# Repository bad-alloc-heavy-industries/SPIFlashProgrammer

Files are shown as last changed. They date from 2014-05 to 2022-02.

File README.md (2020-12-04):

# SPI Flash Programmer

After a complete rewrite and re-hash of the original ideal having had it proove itself, a PCB and tightly integrated yet simple to use firmware is the name of the game.

SPIFlashProgrammer is a small but capable board housing a Texas Instruments Tiva-C series ARM microprocessor, two Flash devices for use in a production environment to allow one board to program up to two different target devices on a production line, and USB for power and connecting to a host machine.

When connected to a host, the USB connectivity and `flashprog` utility come together to form a sleak programming experience, allowing the tool to be used in a "set and forget" manner for test and debug of bitstreams and firmware.

## Flash chip support

The firmware targets 25 series memory devices such as the M25P16, W25Q80BV, and AT25SF641.

## Build and installation

Building requires a small number of prerequsites and dependencies:

* [Meson](https://meson.build)
* [Ninja](https://ninja-build.org)
* A modern arm-none-eabi GCC such as the [GNU ARM Embedded Toolchain](https://developer.arm.com/tools-and-software/open-source-software/developer-tools/gnu-toolchain/gnu-rm)
	or any distro or custom build GCC capable of targeting ARMv7 via C++17

To build the firmware and host software, run

```Bash
meson build --cross-file=cross-files/arm-none-eabi.meson
ninja -C build
```

You may then use the results in-place, or install the host software with `ninja -C build install`.

Programming the firmware onto a newly minted board can be achived via any JTAG adapter that can talk TI ICDI.
We use the awesome [Black Magic Probe](https://github.com/blacksphere/blackmagic) with the toolchain GDB.

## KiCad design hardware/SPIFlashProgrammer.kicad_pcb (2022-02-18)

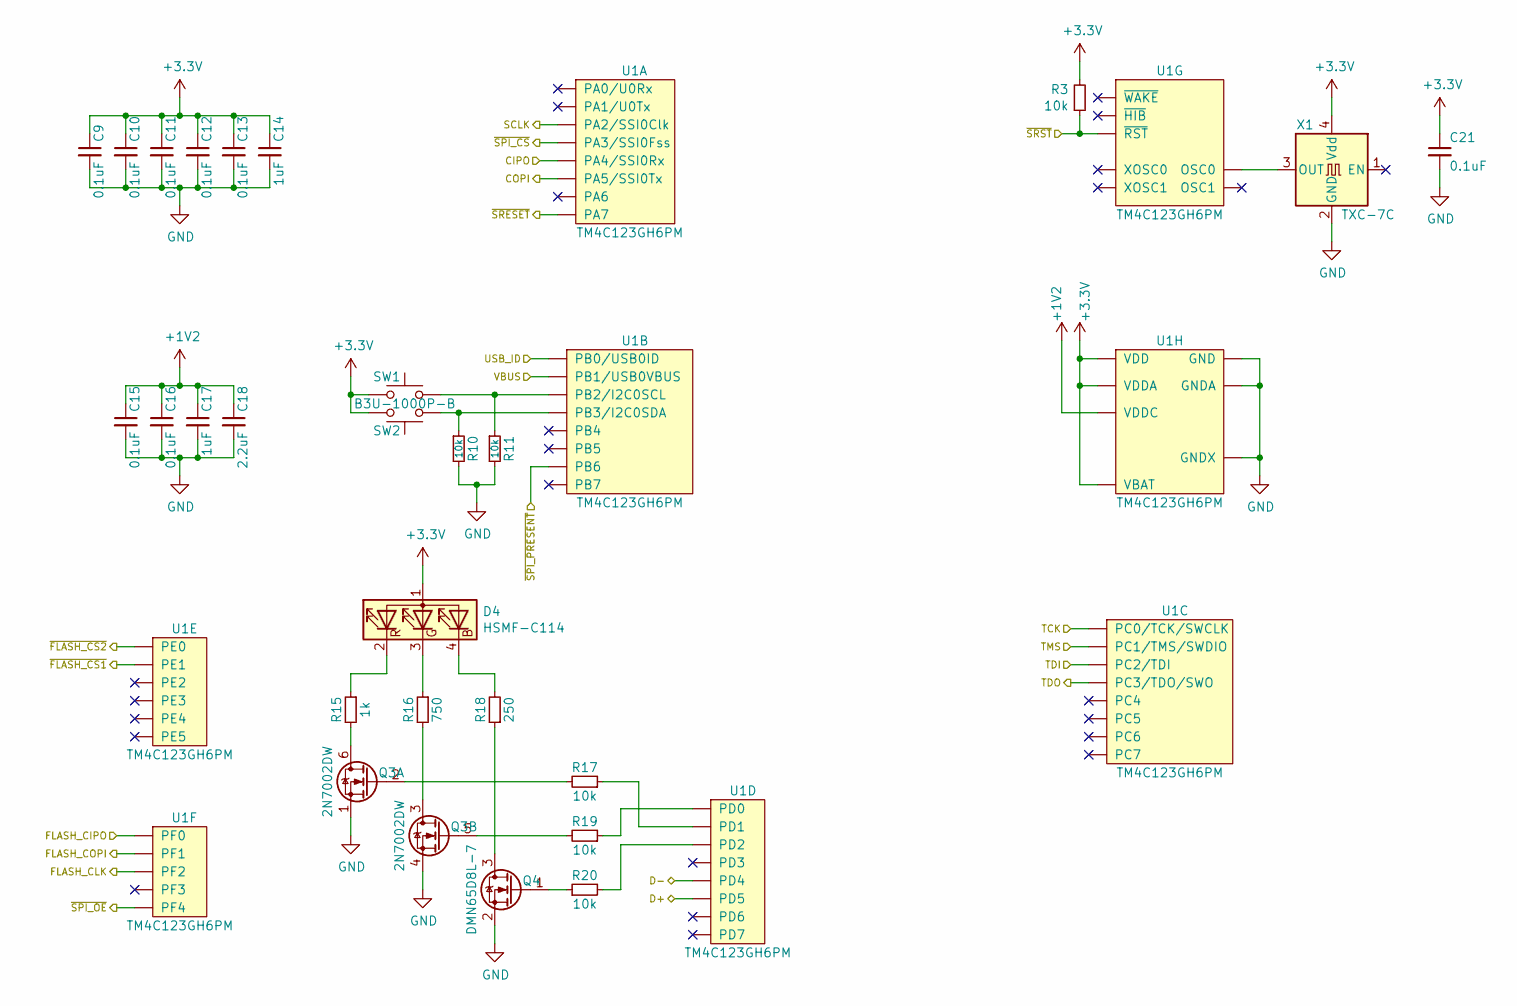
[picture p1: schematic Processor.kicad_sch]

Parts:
C9, C10, C11, C12, C13, C15, C16, C21: 0.1uF; C0603; MPN MC0603B104J250CT
C14, C17: 1uF; C0603; MPN MC0603B105K160CT
C18: 2.2uF; C0603; MPN C1608X5R1C225K080AB
D4: HSMF-C114; LED0606; MPN HSMF-C114
Q3: 2N7002DW; SOT-363_SC-70-6; MPN 2N7002DW
Q4: DMN65D8L-7; SOT-23; MPN DMN65D8L-7
R3, R10, R11, R17, R19, R20: 10k; R0603; MPN MC0063W0603110K
R15: 1k; R0603; MPN MC0063W0603110K
R16: 750; R0603; MPN MC0063W0603110K
R18: 250; R0603; MPN MC0063W0603110K
SW1, SW2: B3U-1000P-B; MPN B3U-1000P-B
U1: TM4C123GH6PM; QFP-64_10.2x10.2_Pitch0.5mm; MPN TM4C123GH6PM
X1: TXC-7C; SMD3225; MPN MCSJK-3N-25.00-3.3-50-B

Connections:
+1V2: C15.1, C16.1, C17.1, C18.1, U1.25 (VDDC), U1.56 (VDDC)
+3V3: C9.1, C10.1, C11.1, C12.1, C13.1, C14.1, C21.1, D4.1 (A), R3.2, SW1.1, SW2.1, U1.2 (VDDA), U1.11 (VDD), U1.26 (VDD), U1.37 (VBAT), U1.42 (VDD), U1.54 (VDD), X1.4 (Vdd); also elsewhere on the board
/Connectors/CIPO: U1.21 (PA4/SSI0Rx); also elsewhere on the board
/Connectors/COPI: U1.22 (PA5/SSI0Tx); also elsewhere on the board
/Connectors/D+: U1.44 (PD5); also elsewhere on the board
/Connectors/D-: U1.43 (PD4); also elsewhere on the board
/Connectors/SCLK: U1.19 (PA2/SSI0Clk); also elsewhere on the board
/Connectors/TCK: U1.52 (PC0/TCK/SWCLK); also elsewhere on the board
/Connectors/TDI: U1.50 (PC2/TDI); also elsewhere on the board
/Connectors/TDO: U1.49 (PC3/TDO/SWO); also elsewhere on the board
/Connectors/TMS: U1.51 (PC1/TMS/SWDIO); also elsewhere on the board
/Connectors/USB_ID: U1.45 (PB0/USB0ID); also elsewhere on the board
/Connectors/VBUS: U1.46 (PB1/USB0VBUS); also elsewhere on the board
/Connectors/~SPI_CS: U1.20 (PA3/SSI0Fss); also elsewhere on the board
/Connectors/~SPI_OE: U1.5 (PF4); also elsewhere on the board
/Connectors/~SPI_PRESENT: U1.1 (PB6); also elsewhere on the board
/Connectors/~SRESET: U1.24 (PA7); also elsewhere on the board
/Connectors/~SRST: R3.1, U1.38 (~RST); also elsewhere on the board
/Onboard Flash/CIPO: U1.28 (PF0); also elsewhere on the board
/Onboard Flash/COPI: U1.29 (PF1); also elsewhere on the board
/Onboard Flash/SCK: U1.30 (PF2); also elsewhere on the board
/Onboard Flash/~CS1: U1.8 (PE1); also elsewhere on the board
/Onboard Flash/~CS2: U1.9 (PE0); also elsewhere on the board
GND: C9.2, C10.2, C11.2, C12.2, C13.2, C14.2, C15.2, C16.2, C17.2, C18.2, C21.2, Q3.1 (S), Q3.4 (S), Q4.2 (S), R10.2, R11.2, U1.3 (GNDA), U1.12 (GND), U1.27 (GND), U1.35 (GNDX), U1.39 (GND), U1.55 (GND), X1.2 (GND); also elsewhere on the board
unnamed: D4.2 (RK), R15.1
unnamed: D4.3 (GK), R16.1
unnamed: D4.4 (BK), R18.2
unnamed: Q3.2 (G), R17.2
unnamed: Q3.3 (D), R16.2
unnamed: Q3.5 (G), R19.2
unnamed: Q3.6 (D), R15.2
unnamed: Q4.1 (G), R20.1
unnamed: Q4.3 (D), R18.1
unnamed: R10.1, SW2.2, U1.48 (PB3/I2C0SDA)
unnamed: R11.1, SW1.2, U1.47 (PB2/I2C0SCL)
unnamed: R17.1, U1.62 (PD1)
unnamed: R19.1, U1.61 (PD0)
unnamed: R20.2, U1.63 (PD2)
unnamed: U1.40 (OSC0), X1.3 (OUT)

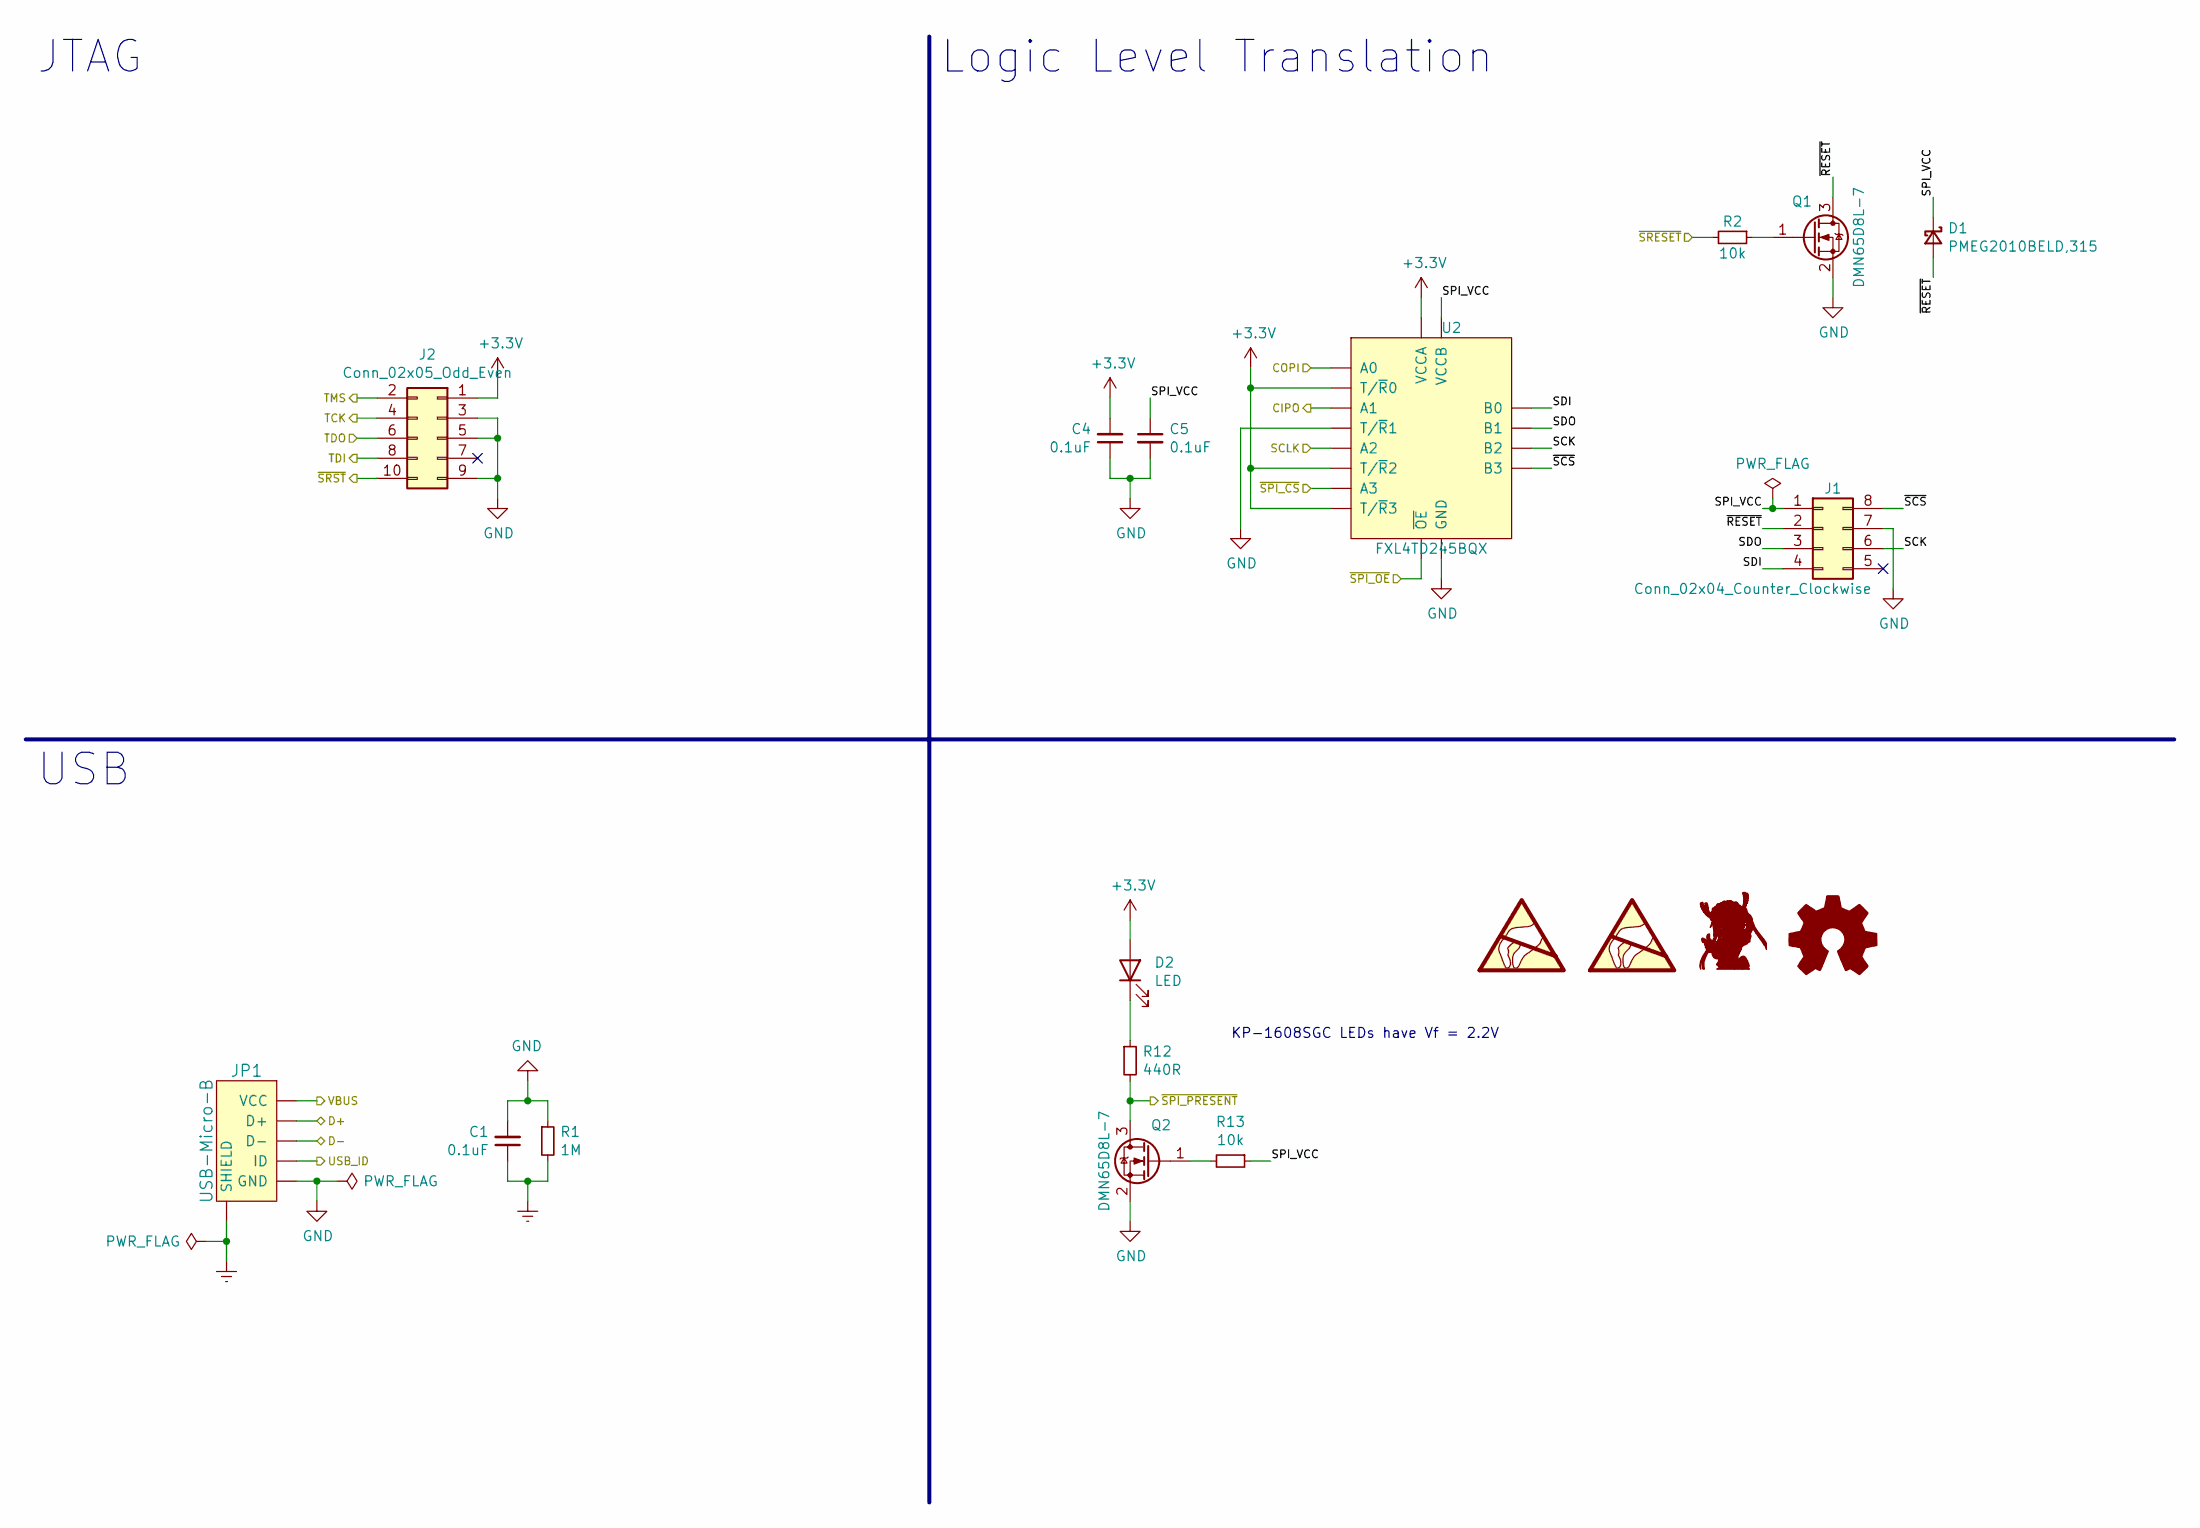
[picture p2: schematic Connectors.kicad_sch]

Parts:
C1, C4, C5: 0.1uF; C0603; MPN MC0603B104J250CT
D1: PMEG2010BELD,315; SOD882D_DFN1006D-2; MPN PMEG2010BELD,315
D2: LED; LED0603; MPN KP-1608SGC
DRG1: トール; トール-8.6x9.9
J1: Conn_02x04_Counter_Clockwise; 75867-132LF; MPN 75867-132LF
J2: Conn_02x05_Odd_Even; PinSocket_2x05_P1.27mm_Vertical_SMD; MPN 20021321-00010C4LF
JP1: USB-Micro-B; MICRO-USB-B-(IN_PCB); MPN 10103593-0001LF
LOGO1: Logo_Open_Hardware_Small; OSHW-Symbol_6.7x6mm_SilkScreen
Q1, Q2: DMN65D8L-7; SOT-23; MPN DMN65D8L-7
R1: 1M; R0603; MPN MCWR06X1004FTL
R2, R13: 10k; R0603; MPN MC0063W0603110K
R12: 440R; R0603; MPN MCWR06X4700FTL
SYM1: SYM_ESD_Small; WEEE-Logo_4.2x6mm_SilkScreen
SYM2: SYM_ESD_Small; ESD-Logo_6.6x6mm_SilkScreen
U2: FXL4TD245BQX; DQFN16_1EP_2.5x3.5mm_P0.5mm; MPN FXL4TD245BQX

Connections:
+3V3: C4.2, D2.2 (A), J2.1, U2.1 (VCCA), U2.2 (T/~R0), U2.7 (T/~R3), U2.10 (T/~R2); also elsewhere on the board
/Connectors/CIPO: U2.4 (A1); also elsewhere on the board
/Connectors/COPI: U2.3 (A0); also elsewhere on the board
/Connectors/D+: JP1.D+; also elsewhere on the board
/Connectors/D-: JP1.D-; also elsewhere on the board
/Connectors/SCK: J1.6, U2.12 (B2)
/Connectors/SCLK: U2.5 (A2); also elsewhere on the board
/Connectors/SDI: J1.4, U2.14 (B0)
/Connectors/SDO: J1.3, U2.13 (B1)
/Connectors/SPI_VCC: C5.1, D1.1 (K), J1.1, R13.1, U2.16 (VCCB)
/Connectors/TCK: J2.4; also elsewhere on the board
/Connectors/TDI: J2.8; also elsewhere on the board
/Connectors/TDO: J2.6; also elsewhere on the board
/Connectors/TMS: J2.2; also elsewhere on the board
/Connectors/USB_ID: JP1.ID; also elsewhere on the board
/Connectors/VBUS: JP1.VCC; also elsewhere on the board
/Connectors/~RESET: D1.2 (A), J1.2, Q1.3 (D)
/Connectors/~SCS: J1.8, U2.11 (B3)
/Connectors/~SPI_CS: U2.6 (A3); also elsewhere on the board
/Connectors/~SPI_OE: U2.9 (~OE); also elsewhere on the board
/Connectors/~SPI_PRESENT: Q2.3 (D), R12.2; also elsewhere on the board
/Connectors/~SRESET: R2.2; also elsewhere on the board
/Connectors/~SRST: J2.10; also elsewhere on the board
Earth: C1.1, JP1.SHIELD, R1.2
GND: C1.2, C4.1, C5.2, J1.7, J2.3, J2.5, J2.9, JP1.GND1 (GND), Q1.2 (S), Q2.2 (S), R1.1, U2.8 (GND), U2.15 (T/~R1), U2.EP (GND); also elsewhere on the board
unnamed: D2.1 (K), R12.1
unnamed: Q1.1 (G), R2.1
unnamed: Q2.1 (G), R13.2

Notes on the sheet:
JTAG
USB
KP-1608SGC LEDs have Vf = 2.2V
Logic Level Translation

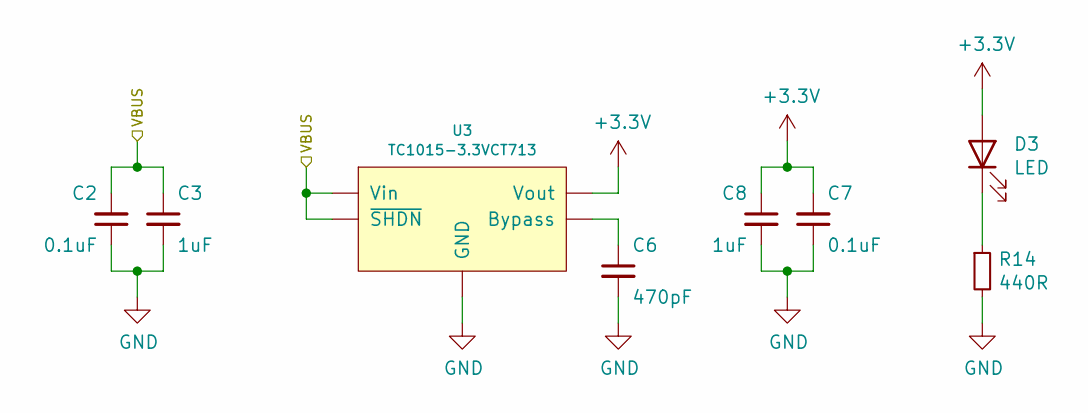
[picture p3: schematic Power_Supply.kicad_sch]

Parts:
C2, C7: 0.1uF; C0603; MPN MC0603B104J250CT
C3, C8: 1uF; C0603; MPN MC0603B105K160CT
C6: 470pF; C0603; MPN MC0603B471J500CT
D3: LED; LED0603; MPN KP-1608SGC
R14: 440R; R0603; MPN MCWR06X4700FTL
U3: TC1015-3.3VCT713; SOT-23-5; MPN TC1015-3.3VCT713

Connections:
+3V3: C7.2, C8.1, D3.2 (A), U3.5 (Vout); also elsewhere on the board
/Connectors/VBUS: C2.2, C3.1, U3.1 (Vin), U3.3 (~SHDN); also elsewhere on the board
GND: C2.1, C3.2, C6.2, C7.1, C8.2, R14.2, U3.2 (GND); also elsewhere on the board
unnamed: C6.1, U3.4 (Bypass)
unnamed: D3.1 (K), R14.1

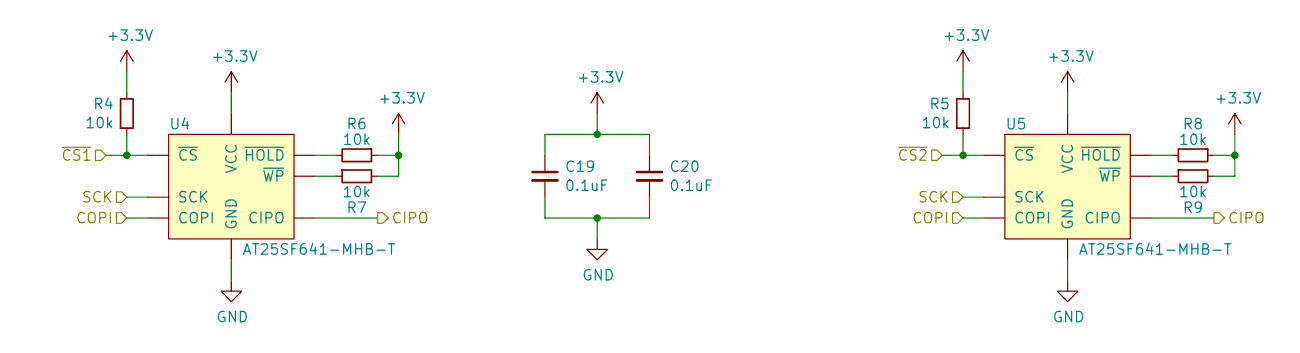
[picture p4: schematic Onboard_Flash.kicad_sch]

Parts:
C19, C20: 0.1uF; C0603; MPN MC0603B104J250CT
R4, R5, R6, R7, R8, R9: 10k; R0603; MPN MC0063W0603110K
U4, U5: AT25SF641-MHB-T; UDFN-8-1EP_6x5mm_P1.27mm_EP3.4x4mm; MPN AT25SF641-MHB-T

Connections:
+3V3: C19.1, C20.1, R4.2, R5.2, R6.1, R7.2, R8.1, R9.2, U4.8 (VCC), U5.8 (VCC); also elsewhere on the board
/Onboard Flash/CIPO: U4.2 (CIPO), U5.2 (CIPO); also elsewhere on the board
/Onboard Flash/COPI: U4.5 (COPI), U5.5 (COPI); also elsewhere on the board
/Onboard Flash/SCK: U4.6 (SCK), U5.6 (SCK); also elsewhere on the board
/Onboard Flash/~CS1: R4.1, U4.1 (~CS); also elsewhere on the board
/Onboard Flash/~CS2: R5.1, U5.1 (~CS); also elsewhere on the board
GND: C19.2, C20.2, U4.4 (GND), U4.9 (GND), U5.4 (GND), U5.9 (GND); also elsewhere on the board
unnamed: R6.2, U4.7 (~HOLD)
unnamed: R7.1, U4.3 (~WP)
unnamed: R8.2, U5.7 (~HOLD)
unnamed: R9.1, U5.3 (~WP)

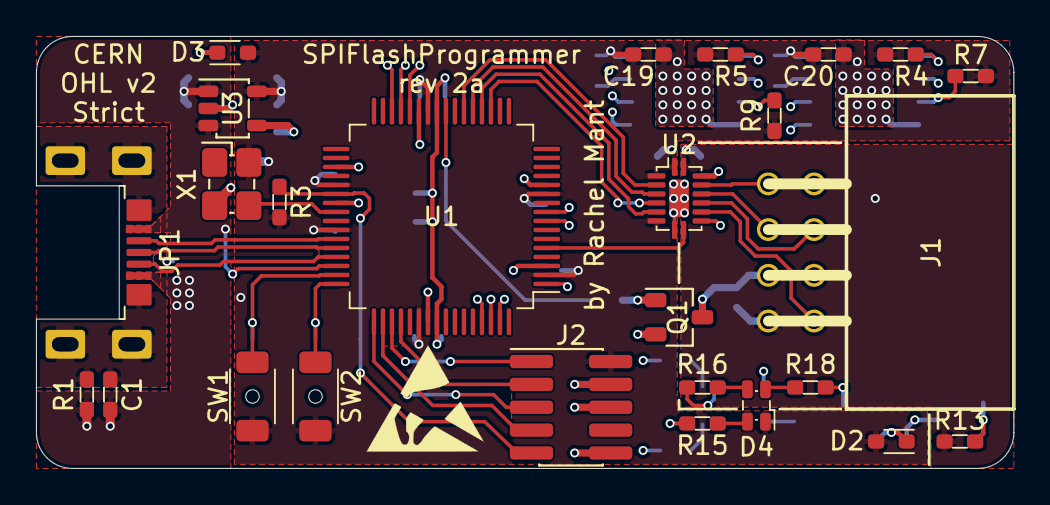
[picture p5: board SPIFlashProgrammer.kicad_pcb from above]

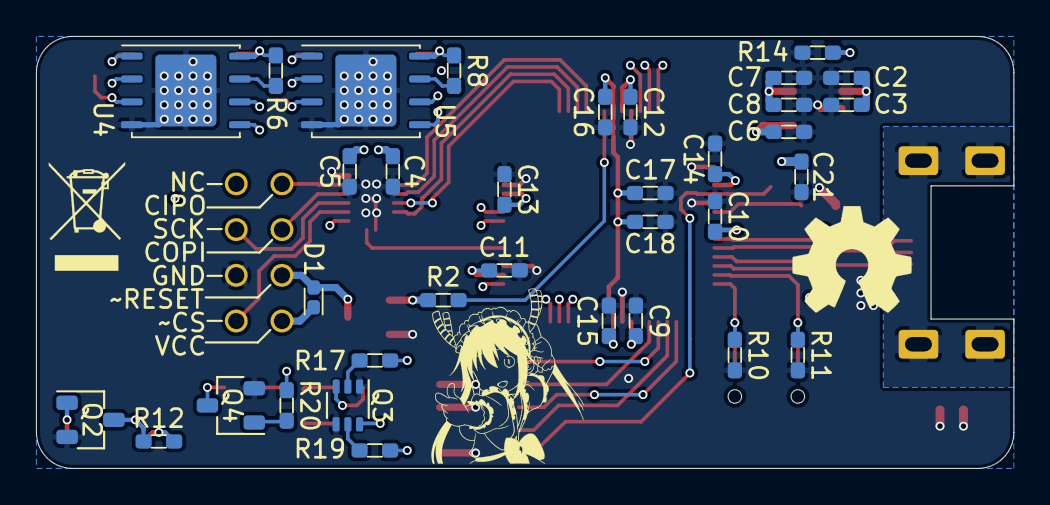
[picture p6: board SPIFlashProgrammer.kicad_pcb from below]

Board: 4 copper layers, 54.3 x 24.0 mm, 64 parts (37 on the bottom side), 55 nets.

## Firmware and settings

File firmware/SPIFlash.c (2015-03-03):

/*
 * This file is part of SPI Flash Programmer (SPIFP)
 * Copyright © 2014 Rachel Mant (dx-mon@users.sourceforge.net)
 *
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
 * You should have received a copy of the GNU General Public License
 * along with this program.  If not, see <http://www.gnu.org/licenses/>.
 */

#include <stdint.h>
#include <stddef.h>
#include <stdbool.h>
#ifndef NOCONFIG
#include "config.h"
#endif
#ifndef NOUSB
#include "USBInterface.h"
#include "UART.h"
#endif
#include "SPI.h"
#include "GPIO.h"

typedef enum
{
	DEV_INVALID,
	DEV_M25P80,
	DEV_M25P16,
	DEV_W25Q80BV,
} FlashDevice_t;

#define WREN	0x06
#define WRDI	0x04
/* 0x9F is the JEDEC guaranteed instruction for reading device ID info. */
#define RDID	0x9F
#define RDSR	0x05
#define WRSR	0x01
#define READ	0x03
#define PP		0x02
#define SSE		0x20
#define SE		0xD8
#define BE		0xC7

FlashDevice_t device;
#ifndef NOUSB
uint8_t usbData[256];
uint32_t usbDataTotal;
uint32_t usbDataReceived;
#endif

/*
 * 0x20 => Manufacturer ID (Numonyx)
 * 0x20 => Memory Type (SPI Flash)
 * 0x14 => Memory Capacity - 8Mbit
 */
static const uint8_t M25P80_DID[3] = { 0x20, 0x71, 0x14 };
/*
 * 0x20 => Manufacturer ID (Numonyx)
 * 0x20 => Memory Type (SPI Flash)
 * 0x15 => Memory Capacity - 16Mbit
 */
static const uint8_t M25P16_DID[3] = { 0x20, 0x20, 0x15 };
/*
 * 0xEF => Winbond
 * 0x40 => SPIFlash
 * 0x14 => 8Mbit
 */
static const uint8_t W25Q80BV_DID[3] = { 0xEF, 0x40, 0x14 };

int datacmp(const uint8_t *a, const uint8_t *b, const size_t n)
{
	size_t i;
	for (i = 0; i < n; i++)
	{
		if (*a != *b)
			return *a - *b;
		a++;
		b++;
	}
	return 0;
}

#ifndef NOUSB
uint16_t readData()
{
	uint8_t pageLen, i;
	if (uartRead() != CMD_PAGE)
		return 0;
	pageLen = uartRead();
	i = 0;
	do
	{
		usbData[i] = uartRead();
		i++;
	}
	while (i != pageLen);

	if (pageLen == 0)
		return 0x100;
	else
		return pageLen;
}
#endif

bool verifyDID()
{
	uint8_t data[3], i;
	/* Select the device */
	spiChipSelect(true);
	/* Send a JEDEC DID read request */
	spiWrite(RDID);
	/* For each of the three bytes returned */
	for (i = 0; i < 3; i++)
		/* And having recieved the answer, buffer it */
		data[i] = spiRead();
	/* Deselect the device */
	spiChipSelect(false);
	/* Compare the recieved data to the expected data */
	/* I wanted to use memcmp here, but could not make use of the newlib implemenation */
	if (datacmp(data, M25P80_DID, 3) == 0)
		device = DEV_M25P80;
	else if (datacmp(data, M25P16_DID, 3) == 0)
		device = DEV_M25P16;
	else if (datacmp(data, W25Q80BV_DID, 3) == 0)
		device = DEV_W25Q80BV;
	else
		device = DEV_INVALID;
	return device != DEV_INVALID;
}

void writeEnable()
{
	/* Select the device */
	spiChipSelect(true);
	/* Write enable the device */
	spiWrite(WREN);
	/* Deselect the device - executes write-enable instruction */
	spiChipSelect(false);
	asm("nop");
	/* Select the device again */
	spiChipSelect(true);
	/* Issue Read Status Register instruction */
	spiWrite(RDSR);
	/* And use it's continuous read mode till the write enable completes (bit 1 => 1) */
	while ((spiRead() & 0x02) == 0);
	/* Deselect the device */
	spiChipSelect(false);
}

void unlockDevice()
{
	writeEnable();
	/* Select the device */
	spiChipSelect(true);
	/* Write the Status Register */
	spiWrite(WRSR);
	/* All zeros disables all enabled protections */
	spiWrite(0x00);
	/* Deselect the device */
	spiChipSelect(false);
}

void lockDevice()
{
	writeEnable();
	/* Select the device */
	spiChipSelect(true);
	/* Write the Status Register */
	spiWrite(WRSR);
	/* The three Block Protect bits are bits [4:2] */
	spiWrite(0x1C);
	/* Deselect the device */
	spiChipSelect(false);
}

void eraseDevice(const uint8_t *data)
{
	uint8_t i;
	/* Ensure the device is write enabled */
	writeEnable();
	/* Select the device */
	spiChipSelect(true);
	/* Issue erase instruction */
	spiWrite(BE);
	/* Deselect the device - executes erase */
	spiChipSelect(false);
	for (i = 0; i < 10; i++);
	/* Select the device */
	spiChipSelect(true);
	/* Write the Read Status Register instruction */
	spiWrite(RDSR);
	/* While write is not complete (bit 0 => 1) */
	while ((spiRead() & 0x01) != 0)
	{
#ifndef NOUSB
		if (data == usbData && uartHaveData())
		{
			/* It doesn't matter what the request was.. */
			uartRead();
			/* Inform the connected PC */
			uartWrite(CMD_ERASE);
			uartWrite(RPL_BUSY);
		}
#endif
	}
	/* Deselect the device */
	spiChipSelect(false);
#ifndef NOUSB
	if (data == usbData)
	{
		/* It doesn't matter what the request was.. */
		uartRead();
		/* Write complete, so say erase completed! */
		uartWrite(CMD_ERASE);
		uartWrite(RPL_OK);
	}
#endif
}

void writeData(const uint8_t sector, const uint8_t page, const uint8_t *data, const uint16_t dataLen)
{
	uint16_t i;
	writeEnable();
	/* Select the device */
	spiChipSelect(true);
	/* And issue the Page Program instruction */
	spiWrite(PP);
	/* Sector is (sector >> 4), and sub-sector is (sector & 0x0F) */
	spiWrite(sector);
	/* The page of the sector */
	spiWrite(page);
	/* Must be 0 to select the first byte of the page */
	spiWrite(0);
	/* Send the data */
	for (i = 0; i < dataLen; i++)
		spiWrite(data[i]);
	/* Deselect the device - executes write instruction */
	spiChipSelect(false);
}

bool verifyData(const uint16_t startPage, const uint8_t *data, const size_t dataLen)
{
	uint16_t i;
	bool ok = true;
	/* Select the device */
	spiChipSelect(true);
	spiWrite(READ);
	spiWrite(startPage >> 8);
	spiWrite(startPage & 0xFF);
	spiWrite(0);
	for (i = 0; i < dataLen; i++)
	{
		if (spiRead() != data[i])
		{
			ok = false;
			break;
		}
	}
	/* Deselect the device */
	spiChipSelect(false);
	return ok;
}

void waitWriteComplete()
{
	/* Select the device */
	spiChipSelect(true);
	/* Write the Read Status Register instruction */
	spiWrite(RDSR);
	/* And use it's continuous read mode till the write is complete (bit 0 => 0) */
	while ((spiRead() & 0x01) != 0);
	/* Deselect the device */
	spiChipSelect(false);
}

void transferBitfile(const void *data, const size_t dataLen)
{
	uint16_t addr, pages;
#ifndef NOCONFIG
	const uint8_t *dataPtr = data;
#endif
#ifndef NOUSB
	bool programmed = true;
#endif

	if (!verifyDID())
	{
#ifndef NOUSB
		if (data == usbData)
		{
			uartWrite(CMD_ABORT);
			uartWrite(RPL_FAIL);
		}
#endif
		return;
	}
#ifndef NOUSB
	else if (data == usbData)
	{
		uartWrite(CMD_START);
		uartWrite(RPL_OK);
	}
#endif

	pages = (dataLen >> 8) + ((dataLen & 0xFF) != 0 ? 1 : 0);
	if (device == DEV_M25P80)
	{
		unlockDevice();
		waitWriteComplete();
	}
	eraseDevice(data);
	for (addr = 0; addr < pages; addr++)
	{
#ifndef NOUSB
		size_t pageLen;
		if (data == usbData)
		{
			pageLen = readData();
			/* If we failed to receive the page, immediately indicate failure */
			if (pageLen == 0)
			{
				uartWrite(CMD_PAGE);
				uartWrite(RPL_FAIL);
				programmed = false;
				break;
			}
			writeData(addr >> 8, addr & 0xFF, data, pageLen);
		}
#endif
#ifndef NOCONFIG
		if (data == config)
		{
			if ((addr + 1) < (dataLen >> 8))
				writeData(addr >> 8, addr & 0xFF, dataPtr, 256);
			else
				writeData(addr >> 8, addr & 0xFF, dataPtr, dataLen & 0xFF);
			dataPtr += 256;
		}
#endif
		waitWriteComplete();
#ifndef NOUSB
		if (data == usbData)
		{
			if (!verifyData(addr, data, pageLen))
			{
				uartWrite(CMD_ABORT);
				uartWrite(RPL_FAIL);
				programmed = false;
				break;
			}
			else
			{
				uartWrite(CMD_PAGE);
				uartWrite(RPL_OK);
				usbDataReceived += pageLen;
			}
		}
#endif
	}
	if (device == DEV_M25P80)
	{
		lockDevice();
		waitWriteComplete();
	}
#ifndef NOCONFIG
	if (data == config)
	{
		if (verifyData(0, data, dataLen))
			gpioShowOK();
	}
#endif
#ifndef NOUSB
	if (data == usbData)
	{
		uint8_t cmd = uartRead();
		if (cmd == CMD_STOP)
		{
			uint8_t i;
			uint32_t diff = usbDataTotal - usbDataReceived;
			for (i = 0; i < 4; i++)
			{
				uartWrite((diff >> 24) & 0xFF);
				diff <<= 8;
			}
			uartWrite(CMD_STOP);
			if (programmed)
			{
				uartWrite(RPL_OK);
				gpioShowOK();
			}
			else
				uartWrite(RPL_FAIL);
		}
		else
		{
			uartWrite(CMD_INVALID);
			uartWrite(RPL_FAIL);
		}
	}
#endif
}

int main()
{
	gpioInit();
	spiInit();
#ifndef NOUSB
	uartInit();
#endif

	while (1)
	{
#ifndef NOCONFIG
		/* If either button has been pressed.. */
		if (gpioCanTransfer())
		{
			gpioStopTimer();
			gpioBeginTransfer();
			gpioSignalTransfer();
			/* Attempt the transfer */
			transferBitfile(config, configLen);
			gpioEndTransfer();
			gpioStartTimer();
		}
#endif
#ifndef NOUSB
		/* If the UART has recieved a byte.. */
		if (uartHaveData())
		{
			if (uartPeak() == CMD_START)
			{
				uint8_t i;
				gpioStopTimer();
				gpioBeginTransfer();
				usbDataTotal = 0;
				usbDataReceived = 0;
				for (i = 0; i < 4; i++)
				{
					usbDataTotal <<= 8;
					usbDataTotal |= uartRead();
				}
				gpioSignalTransfer();
				transferBitfile(usbData, usbDataTotal);
				gpioEndTransfer();
				gpioStartTimer();
			}
			else
			{
				uartWrite(CMD_INVALID);
				uartWrite(RPL_FAIL);
			}
		}
#endif
		gpioCheckIdle();
	}

	return 0;
}

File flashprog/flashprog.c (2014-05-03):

/*
 * This file is part of SPI Flash Programmer (SPIFP)
 * Copyright © 2014 Rachel Mant (dx-mon@users.sourceforge.net)
 *
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
 * You should have received a copy of the GNU General Public License
 * along with this program.  If not, see <http://www.gnu.org/licenses/>.
 */

#include <stdio.h>
#include <fcntl.h>
#include <unistd.h>
#include <sys/types.h>
#include <sys/stat.h>

#include "strUtils.h"
#include "USB.h"
#include "USBInterface.h"

#ifdef _MSC_VER
#define _usleep _sleep
#else
#define MSECS_IN_SEC 1000
#define NSECS_IN_MSEC 1000000
#define _usleep(milisec) \
	{\
		struct timespec req = {milisec / MSECS_IN_SEC, (milisec % MSECS_IN_SEC) * NSECS_IN_MSEC}; \
		nanosleep(&req, NULL); \
	}
#endif

/*
 * USB transfer protocol:
 *
 * CMD_START + 4 bytes => uint32_t length of data total
 * CMD_PAGE + 1 bytes + up to 256 bytes => uint8_t page length (0 == 256), page data
 * CMD_ABORT => Sent to indicate user requested to abort
 * CMD_STOP => Sent at the end of transfering all the data to indicate we think we've finished.
 *   Device replies with some data indicating the status of the flash device and if there are any remaining expected bytes.
 *
 * After sending each command, including CMD_STOP, the device must respond with the command code and a byte indicating whether
 * it could execute it correctly - 1 for OK, 0 for error.
 */
int dataFD;
size_t dataLen;

/* Reserve enough space for a page of data */
unsigned char data[256];

static const uint8_t numProgChars = 4;
static const char *progressChars = "|/-\\";
uint8_t progChar;

int usage(char *prog)
{
	printf("Usage:\n"
		"\t%s binfile.bin\n", prog);
	return 1;
}

void tick()
{
	printf("%c\b", progressChars[progChar]);
	fflush(stdout);
	progChar = ++progChar % numProgChars;
}

void processFile()
{
	int32_t res, blockLen = -1;
	uint32_t pageNum = 0;
	progChar = 0;
	printf("Programming: ");
	while (blockLen != 0)
	{
		blockLen = read(dataFD, data, 256);
		if (blockLen == -1)
		{
			usbWriteByte(CMD_ABORT);
			die("\rError: read() returned an error.. cannot continue..\n");
		}
		else if (blockLen == 0)
			continue;
		usbWriteByte(CMD_PAGE);
		usbWriteByte(blockLen & 0xFF);
		usbWrite(data, blockLen);
		res = usbRead(data, 2);
		if (res != 2 || data[0] != CMD_PAGE || data[1] != RPL_OK)
		{
			printf("\rError: Programming a data page failed\n");
			break;
		}
		else
		{
			pageNum++;
			if ((pageNum % 4) == 0)
				tick();
		}
	}
}

void waitForErase()
{
	int32_t res;
	progChar = 0;
	printf("Erasing: ");
	fflush(stdout);
	do
	{
		usbWriteByte(CMD_ERASE);
		res = usbRead(data, 2);
		if (res != 2 || data[0] != CMD_ERASE)
			die("\rError: Erase cycle interrupted, cannot continue..\n");
		else if (data[1] == RPL_OK)
			break;
		tick();
		_usleep(100);
	}
	while (data[1] == RPL_BUSY);
	printf("Done!\n");
}

void writeLength()
{
	data[0] = (dataLen >> 24) & 0xFF;
	data[1] = (dataLen >> 16) & 0xFF;
	data[2] = (dataLen >> 8) & 0xFF;
	data[3] = dataLen & 0xFF;
	usbWrite(data, 4);
}

int main(int argc, char **argv)
{
	int32_t res;
	struct stat dataStat;

	if (argc != 2)
		return usage(argv[0]);
	usbInit();
	dataFD = open(argv[1], O_RDONLY | O_EXCL);
	if (dataFD == -1)
	{
		usbDeinit();
		die("Error: Could not open the file specified\n");
	}
	if (stat(argv[1], &dataStat) != 0)
	{
		close(dataFD);
		usbDeinit();
		die("Error: Could not determine the size of the file specified\n");
	}
	dataLen = dataStat.st_size;

	// Send the start command + 4 bytes indicating how long the data file is
	usbWriteByte(CMD_START);
	writeLength();
	// Now wait for the return code
	res = usbRead(data, 2);
	if (res != 2 || data[0] != CMD_START || data[1] != RPL_OK)
		printf("Tiva C Launchpad said it could not start a transfer\n");
	else
	{
		waitForErase();
		processFile();
		usbWriteByte(CMD_STOP);
		res = usbRead(data, 6);
		if (res != 6 || data[4] != CMD_STOP || data[5] != RPL_OK)
			printf("\rTiva C Launchpad encountered errors during programming, please try again\n");
		else if (*((uint32_t *)data) != 0)
			printf("\rTiva C Launchpad did not receieve whole file\n");
		else
			printf("Done!\n");
	}

	close(dataFD);
	usbDeinit();
	return 0;
}

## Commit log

2014-04-05 Initial commit of the SPI Flash programmer itself.
    Currently this just includes the code needed to intialise the Port A and F GPIO interfaces, and un-gate the SSI0 (SPI0) interface, configuring it as a Freescale SPI interface
2014-04-05 Enabled use of the two buttons on the dev board, and made it so that the LED can be switched to red or green on pressing the buttons (dependant on which is pressed)
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2014-04-06 Checked the datahseet for the SPI Flash device series, and altered the SPI configuration accordingly
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2014-04-06 Restructured the while loop code to activate on either button being pressed and going into the routine we'll use for transfering the bitfile
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2014-04-07 Configured Timer 0 A ready for use to control the timing of the LED reset
    [SPIFlash.c]
2014-04-07 Integrated the new timer configuration into the program to reset the LED back to blue regardless of success of failure after 500us from the completion of a cycle.
    [SPIFlash.c]
2014-04-07 Implemented my own varient of memcmp() named datacmp() and documented verifyDID(). Turns out I can't use my toolchain's libc in this configuration, or if I can I've not figured out how yet without cr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
    [SPIFlash.c]
2014-04-07 Corrected the Port A GPIO configuration to ensure that !CS is an output
    [SPIFlash.c]
2014-04-07 Refactored the SPI IO code into two functions that perform the nitty-gritty and a sequence of calls to those functions
2014-04-07 Added support for starting a write cycle to the SPI Flash device with Write Enable (WREN)
2014-04-07 Implemented a device erase function and support function to allow waiting on the operation to complete
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2014-04-07 Refactored the blob transfer code so it can take an arbitrary buffer rather than the fixed buffer system used before
    [SPIFlash.c]
2014-04-08 Reworked the buffer writer code so that support for the USB version of it is easy to add
    [SPIFlash.c]
2014-04-09 Implemented code for locating, opening and claiming (then cleaning up at the end) the Tiva C debug UART in flashprog
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2014-04-10 Removed the RS232 interface code as while a good idea, it turns out libusb has a better, more powerful transfer mechanism in libusb_bulk_transfer()
2014-04-10 Fixed the build system and removed code that causes the build to fail due to being incomplete
    [USB.c, flashprog.c]
2014-04-10 Added better error handling to the interface claim call in flashprog
    [USB.c]
2014-04-10 Corrected which interface and endpoints the USB IO interface uses
    [USB.c]
2014-04-10 Added configuration directives for enabling the UART on PA[0:1] to the firmware
2014-04-10 Corrected some documentation and wrapped the built-in configuration specific Port F code with #ifndef NOCONFIG
    [SPIFlash.c]
2014-04-10 Fixed an error in the checking logic for the CMD_STOP return value in flashprog
    [flashprog.c]
2014-04-10 Implemented functions to read and write the UART on the Tiva C
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2014-04-11 Implemented checking for programming start failure
    [SPIFlash.c]
2014-04-11 Fixed the insanity that was the preprocessor usage to implement the USB-buffer-specific sections of code in transferBitfile()
    [SPIFlash.c]
2014-04-11 Implemented stub support for handling programming failures during a USB-based programming run
    [SPIFlash.c]
2014-04-11 Corrected my code for handling the normal operation path after the call to verifyDID() on the Tiva C
    [SPIFlash.c]
2014-04-11 Fixed a bug in the UART IO code which was making my UART code think there was always a value waiting to be read in the buffer which results in crashing the processor
    [SPIFlash.c]
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2014-04-11 Added some rudimentary error reporting to the USB IO routines for flashprog
    [USB.c]
2014-04-12 Fixed the packing issue that comes about from different sized struct members causing gaps in the structure when padding is not switched off
    [USB.c]
2014-04-12 Added checks for the CDC structure and switched the interface associations structure to const
2014-04-12 Fixed the mess that was checking the extra_length member for both custom structures
    [USB.c]
2014-04-13 Created the initialisation control flow to set the USB-UART bridge baud rate, byte-width and other control components up in flashprog
2014-04-13 Fixed the reason why the USB IO code was not working - irritating little flaw in the firmware code that's burnt a weekend debugging it
    [SPIFlash.c]
2014-04-13 Added assurances that the correct configuration is entered into by the ICDI component of the interface
    [USB.c]
2014-04-15 Fixed the byte order of the bytes-remaining value sent back from the firmware
    [SPIFlash.c]
2014-04-15 Improved the error detection and reporting for flashprog
    [flashprog.c]
2014-04-15 Added all the code needed to support the transfer of the .bin file over the USB-UART link
2014-04-16 Fixed an error in the firmware which was making the firmware think that the first byte of the first page verified was wrong even when it wasn't
    [SPIFlash.c]
2014-04-16 Corrected how dataLen is transmitted from flashprog to the firmware
    [flashprog.c]
2014-04-16 Fixed the firmware as it was incorrectly issuing the Write Enable instruction - making it so that the instruction never executed
    [SPIFlash.c]
2014-04-19 Configured PA7 as a digital out to allow the Tiva C to reset the target
    [SPIFlash.c]
2014-04-19 Fixed all the SPI oopsies.. to work with the FPGA board, must be configured as Open Collector for data/chip select
    [SPIFlash.c]
2014-04-19 Fixed the SPI bus glitching on us
    [SPIFlash.c]
2014-04-19 Fixed the preprocessor logic surrounding PA7
    [SPIFlash.c]
2014-04-19 Final fixes for the SPI bus setup code to get the whole thing really stable
    [SPIFlash.c]
2014-05-03 Implemented a mechanism to allow for device erasure having not understood the timings for how long Bulk Erase (BE) takes. Datasheet for the Numonyx device this is tested against specifies 8-80s, or f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
    [SPIFlash.c, flashprog.c]
2014-05-03 Corrected the wait condition in waitWriteComplete() and added a call after lockDevice() so the instruction can be assured to have been executed
    [SPIFlash.c]
2014-05-03 Corrected the pin configuration for the SPI clock in the firmware
    [SPIFlash.c]
2014-05-03 Fixed the output of the programming function's error routines in flashprog so the newlines are in the right places
    [flashprog.c]
2014-05-03 Sped up the poll interval to 100ms from 1s in flashprog during device erase which is auto-initiated by the flashing firmware
2014-05-03 Fixed a couple of errors in the README file
2015-01-08 Fixed the precarious delay loop that is designed to wait for WREN completing by instead reading back the status register and waiting for the bit to become set there
    [SPIFlash.c]
2015-01-22 Restructured the build system for the firmware and moved the SPI routines into their own file to allow retargeting to other devices
2015-01-22 Moved the startup code for the Tiva C to it's new home and corrected the build system to match
    [Startup.c]
2015-01-22 Moved the Tiva C specific UART code into it's own file like the SPI code and compensated the build system and main firmware file to match
2015-01-22 Moved the UART initialistaion code for the Tiva C into uartInit() in it's implementation files
2015-01-22 Moved some more of the Tiva C specific UART code into the UART driver file specific to it
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2015-01-22 Added a missing initialisation statement to the UART code as I'd been too efficient at encoding the port direction gubbins
    [UART.c]
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2015-01-23 Added the header for the Tiva C used on the TI Tiva C Launchpad so builds can work out of the gate.
    PLEASE NOTE:
    The license in this file, due to it's origins in TI's TivaWareC pack, is currently likely incompatable with the broader license of this code so may need to be reworked in the future.
2015-02-06 Fixed an off-by-one in the vector handler table, added some missing irqEmptyDef entries and made the hard fault handler a little more useful for when there is an error that causes it to be triggered
    [Startup.c]
2015-02-09 Fixed the need for -Wno-unused-but-set-variable with proper use of __attribute__((unused))
    [SPI.c]
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2015-02-10 Fixed the indentation of the timer constants for the LPC header
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2015-02-25 Implemented the buffer descriptor format for the LPC and fixed a GCC warning about a definitiono doing nothing
    [USBTypes.h]
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2015-02-25 Implemented stubs to handle suspend and wakeup and implemented them into the interrupt handler, fixed up a couple of items in the interrupt handler and documented it all a lot better
    [USB.c]
2015-02-25 Fixed two constants being wrong in the suspend related code
    [USB.c]
2015-02-25 Moved usbSetupPacket_t about as it turns out the uint32_t setup[2]; definition I had is that structure, so fixed this in usbBDTEntry_t
    [USBTypes.h]
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2015-02-26 Fixed whole hosts of oopsies in the definitions for the BDT and transfer descriptor systems
    [USBTypes.h]
2015-02-26 Added a definition for the current packet (usbPacket) being handled and fixed several details of how usbReset() needs to work to make the LPC USB controller happy
    [USB.c]
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2015-02-26 Fixed the lack of the USBRequests.h includein USB.c for LPC making the build fail out due to "Implicit declarations" of the functions implemented therein
    [USB.c]
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2015-02-26 Fixed an uninitialised field warning which is actually really more of an error in this case
    [USBRequests.c]
2015-02-26 Added the missing declarations for the previous commit to USBTypes.h
    [USBTypes.h]
2015-02-26 Implemented the difficult parts of usbRequestSetConfiguration() - buffer and state reset TODO
    [USBRequests.c]
2015-03-01 Sorted out part of the interrupts situation for the LPC so that the USB master interrupt enable bit is correctly set/cleared by usbInit()/usbAttach()
    [USB.c]
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2015-03-03 Added a couple more definitions for the LPC port, which for the time being is going no further as it is taking far too long
    [USB.c]
2015-03-03 Added some new Flash device IDs and fixed my use of the "short RDID" instruction (0x9E) for the JEDEC one (0x9F)
    [SPIFlash.c]
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2020-07-12 Added the schematic and board files from yesterday's stream and the beginnings of v2 of this project
    [Connectors.sch, Processor.sch, SPIFlashProgrammer.kicad_pcb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]
2020-08-30 Clenaed up in and fixed some issues with the connectors sheet, adding the JTAG header and replacing the logic level translator with a more suitable set-direction suite
    [Connectors.sch]
2020-08-30 Added in JTAG connections to the processor
    [Processor.sch]
2020-08-30 Fixed all the top-level wiring that was wrong because the pin types it was connected with were wrong
    [SPIFlashProgrammer.sch]
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2020-08-30 Made some decent progress on the Saturday livestream routing the board
    [SPIFlashProgrammer.kicad_pcb]
2020-10-04 Added the work to the schematic from the last stream, and updated all the footprints to reflect the work going in on my symbol and footprint libraries
    [Connectors.sch, Processor.sch, SPIFlashProgrammer.sch]
2020-10-04 Updated the board with the work done on the last stream
    [SPIFlashProgrammer.kicad_pcb]
2020-10-04 Added the power supply schematic from the last stream
    [Power_Supply.sch]
2020-10-04 Updated the footprints on the board with their new library names
    [SPIFlashProgrammer.kicad_pcb]
2020-10-18 Added the two Flash devices and the user buttons to the schematic
    [Connectors.sch, Onboard_Flash.sch, Power_Supply.sch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]
2020-10-18 Switched to a 4-layer board and completed the layout and routing to handle flash and other bits
    [SPIFlashProgrammer.kicad_pcb]
2020-10-18 Added the bones of the gerbers for the project
    [SPIFlashProgrammer.gbl, SPIFlashProgrammer.gbo, SPIFlashProgrammer.gbs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]
2020-10-21 Added the power LED for the target I missed
    [Connectors.sch]
2020-10-21 Added an LED to indicate the main board power status
    [Power_Supply.sch]
2020-10-21 Added a status LED for the phase of flash programming in progress, and a crystal so the USB peripheral can be used
    [Processor.sch]
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2020-10-21 Laid out and routed all the new parts on the PCB
    [SPIFlashProgrammer.kicad_pcb]
2020-10-21 Fixed some DRC and polygon poor problems
    [SPIFlashProgrammer.kicad_pcb]
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2020-10-26 Cleanup and fixes for ERC errors
    [Connectors.sch, Onboard_Flash.sch, Power_Supply.sch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]
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2020-10-26 Cleanup and fixes to the PCB, including final graphic design
    [SPIFlashProgrammer.kicad_pcb]
2020-10-30 Fixed the choice of license, switching from CERN OHL v1.2 to v2 Strict
2020-10-30 Fixed the state of the BOM for the PCB being horrid
    [Connectors.sch, Onboard_Flash.sch, Power_Supply.sch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]
2020-11-01 Added an interactive BOM for the project
    [SPIFlashProgrammer.kicad_pcb]
2020-11-07 Updated the logic level translator to include the fab layer drawing
    [SPIFlashProgrammer.kicad_pcb]
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2020-11-09 Fixed a couple of issues with the build definition files, and wrote the startup code for the processor
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2020-11-14 Fixed the SPI bus bring-up problems on PortF
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2020-11-15 Fixed some signed-and-bitwise issues in the LED handling
2020-11-16 Fixed the naming of the namespace in the types header, and implemented some helper stuff for the driver stack
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2020-12-05 Begun restructuring the device driver code to work correctly with the Tiva-C USB stack
2020-12-06 Fixed the USB Device driver's bring-up sequencing to allow correct bus attachment and execution of device addressing
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2020-12-06 Fixed some issues with missing brackets around bitwise and boolean operations
2020-12-06 Fixed the issues that were keeping the USB stack from even attaching to the bus and then face-planting on trying to handle any interrupts
2020-12-06 Removed the interactive BOM as it is taking too much repo space up and causing misclassifications
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2020-12-09 Fixed some issues with interrupt handling in the base USB driver
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2020-12-11 Fixed the bug that had the device descriptor sending two trailing bytes and sending the final two bytes of the descriptor wrong
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2020-12-21 Fixed several faux-pas in the handling of USB core/device state tracking and EP0 manipulation
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2021-01-14 Fixed a couple of errors in the linker script for the platform
2021-02-06 Fixed sizing issues with a couple of the descriptor structures which made them unusable
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2021-02-13 Fixed some issues in how reference counting was (not) being handled due to incorrect handling of device objects
2021-02-14 Fixed a bug in the usb::device::setupEndpoint() logic that would have cause it to malfunction for EP2, etc
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2021-02-14 Cleaned up some loose whitespace in the onboard Flash schematic sheet
    [Onboard_Flash.sch]
2021-02-14 Fixed the layout of the RGB LED support components and the values of the resistors for setting the current through the LEDs
    [Processor.sch]
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2021-03-13 Fixed the logic in usb::device::setupEndpoint
2021-03-13 Couple of small fixes about chip reconfiguration for usb::device::handleSetConfiguration()
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2021-03-13 Fixed a couple of small issues with the flashProto code that was causing garbage to happen
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2021-04-11 Fixed a small typo in the SPI Flash driver
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2021-05-08 KiCad file updates
    [SPIFlashProgrammer.kicad_pcb]
2021-05-08 Various KiCad meta fixes
    [Processor.sch]
2021-06-05 Fixed the formatting of the lambda used to get statusCtrlH in the USB device driver
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2021-06-05 Improved the error reporting in the libusb wrapper interrupt transfer routine
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2021-06-30 Switched the flashProto driver to using usb::core::readEPDataAvail() now the hack "fix" has gone away
2021-07-16 Fixed up the code base to work with being bootloaded from the first 8kiB of Flash, and provide the necessary interface for the DFU driver
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2021-09-30 Fixed the zero-size array warnings from the DFU driver
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2021-10-09 Fixed the device listing code for writeDevice()
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2022-01-01 Added a flash chip database to the firmware to help with the page size and capacity detection issues
2022-01-01 Corrected the presence check for an attached external Flash device
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2022-02-14 Stopped the firmware releasing reset on the device after ident when we want to do further operations such as read or erase
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2022-02-14 Fixed a bug where erasing a device and writing to it then erasing a different device would cause the progress bar to be whacky
2022-02-14 Fixed handleTargetDevice() not allowing device deselection
2022-02-15 Theoretically fixed handling of devices > 2^24 bytes such as the W25N01GV
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2022-02-16 Added a SPI present signal for the external bus to the CPU to make detection easier
    [Connectors.sch, Processor.sch, SPIFlashProgrammer.kicad_pcb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]
2022-02-16 Upgraded the KiCad files to v6 format
    [Connectors.kicad_sch, Connectors.sch, Onboard_Flash.kicad_sch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]
2022-02-16 Changed board => hardware to harmonise this project with our others
    [Connectors.kicad_sch, Onboard_Flash.kicad_sch, Power_Supply.kicad_sch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]
2022-02-16 Added control for the level shifter output enable to the CPU to fix problems caused by us accidentally still driving the external bus after reset is released
    [Connectors.kicad_sch, Processor.kicad_sch, SPIFlashProgrammer.kicad_pcb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]
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2022-02-18 Updated the oscillator footprint to bring it in line with KiCad 6 specs
    [SPIFlashProgrammer.kicad_pcb]
2022-04-17 Fixed an issue with how we were doing verification While it worked for smaller devices, devices that need > 16MiB based addressing or which have ECC go wrong with how we were doing it
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2023-01-18 nodiscard and clang-tidy lint fixes for the libusb device holder type
2023-02-05 Fixed some clang-tidy lints in the SPI abstractions of the firmware
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2023-02-07 Fixed the exponetiation issue for the SFDP capacity value with an integral log2() implementation
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2023-05-14 Cleaned up the gerber file situation in the hardware
    [SPIFlashProgrammer.gbl, SPIFlashProgrammer.gbo, SPIFlashProgrammer.gbs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]
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

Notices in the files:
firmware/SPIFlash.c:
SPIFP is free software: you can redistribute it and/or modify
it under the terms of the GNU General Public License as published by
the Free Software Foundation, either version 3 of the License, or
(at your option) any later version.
